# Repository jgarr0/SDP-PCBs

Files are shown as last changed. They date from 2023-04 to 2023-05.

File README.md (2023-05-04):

# SDP-PCBs
Hub and Outlet Motherboard Schematics and PCB Layouts for Smart Power Outlet System
#Hub PCB Schematic


## Hub PCB Layout


## Hub PCB Render


## Assembled hub


## Outlet PCB Schematic


## Outlet PCB Layout


## Outlet PCB Render


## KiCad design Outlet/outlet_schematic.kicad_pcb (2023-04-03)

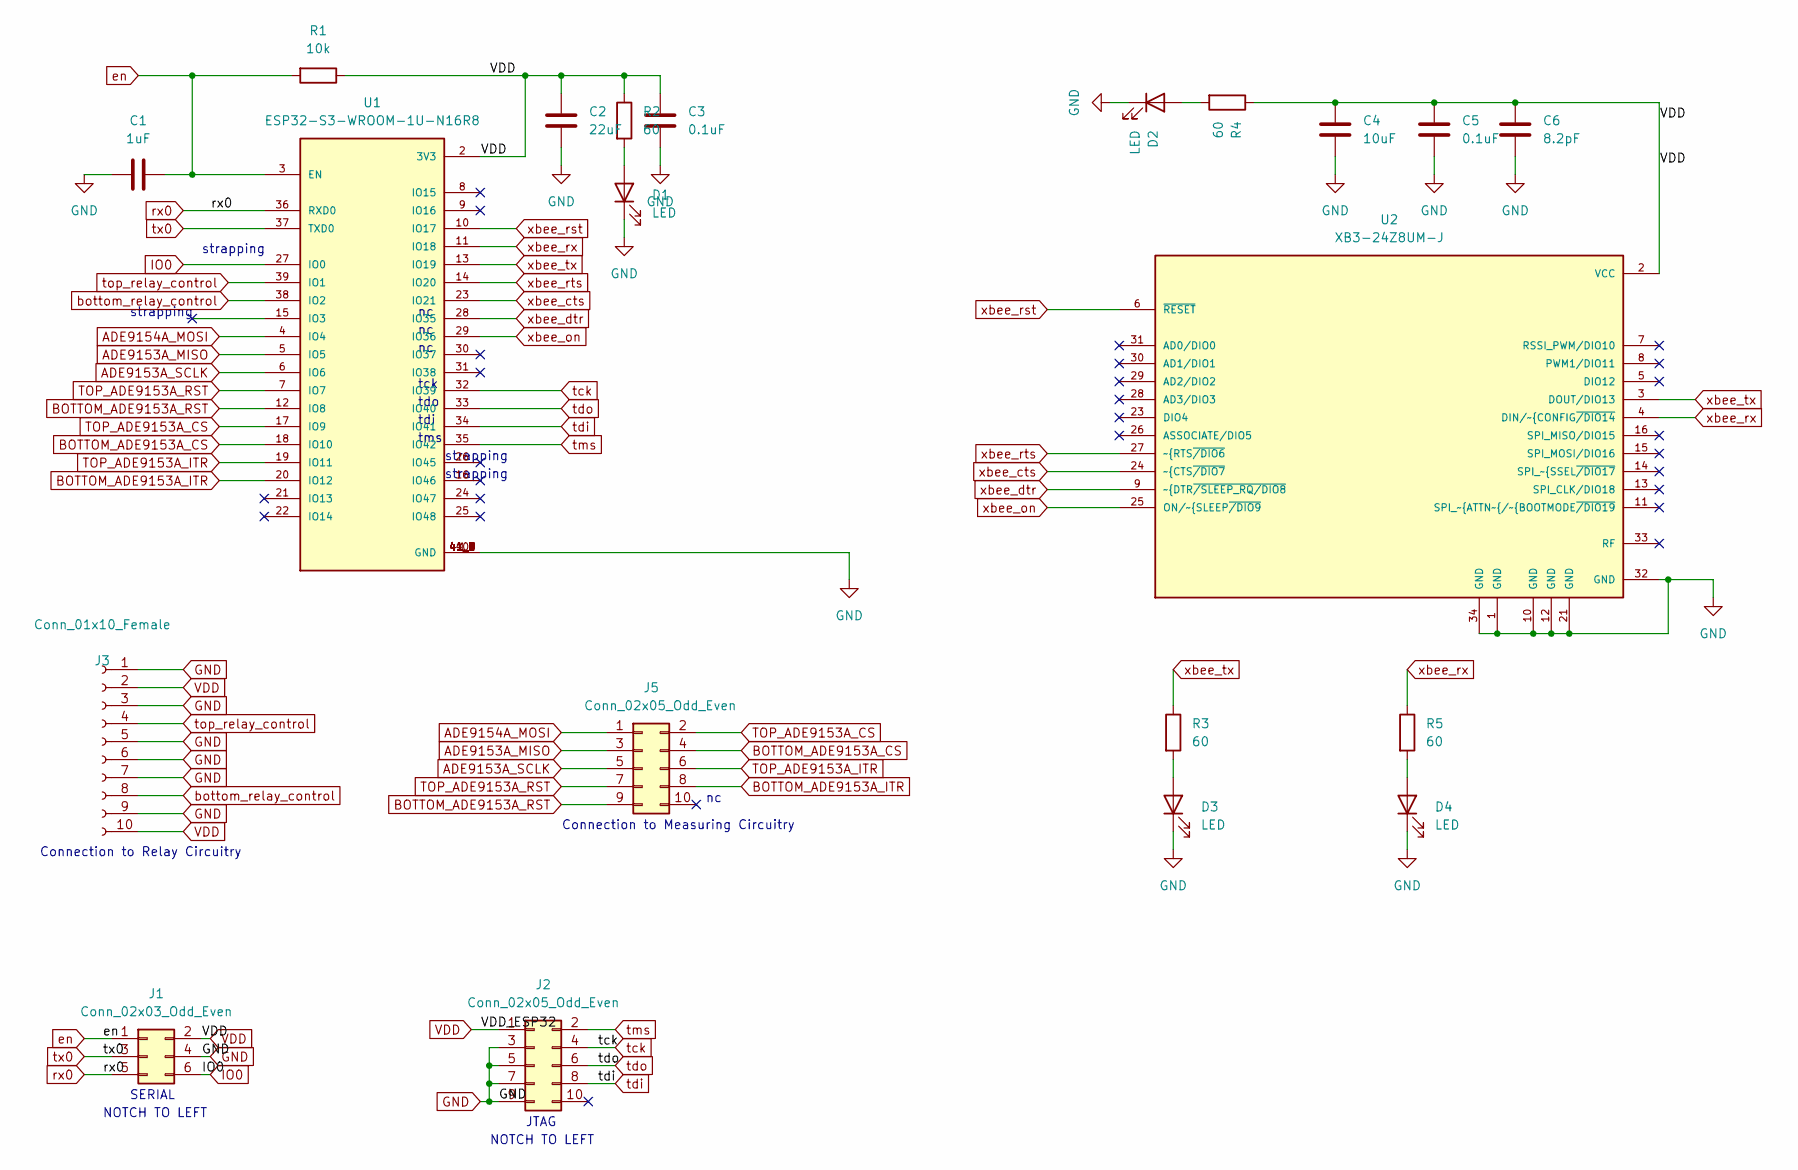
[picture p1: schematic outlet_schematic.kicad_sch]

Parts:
C1: 1uF; C_1206_3216Metric
C2: 22uF; C_1206_3216Metric
C3, C5: 0.1uF; C_1206_3216Metric
C4: 10uF; C_1206_3216Metric
C6: 8.2pF; C_1206_3216Metric
D1, D2, D3, D4: LED; LED_1206_3216Metric
J1: Conn_02x03_Odd_Even; IDC-Header_2x03_P2.54mm_Vertical
J2: Conn_02x05_Odd_Even; IDC-Header_2x05_P2.54mm_Vertical
J3: Conn_01x10_Female; JST_PHD_S10B-PHDSS_2x05_P2.00mm_Horizontal
J5: Conn_02x05_Odd_Even; JST_PHD_S10B-PHDSS_2x05_P2.00mm_Horizontal
R1: 10k; R_1206_3216Metric
R2, R3, R4, R5: 60; R_1206_3216Metric
U1: ESP32-S3-WROOM-1U-N16R8; XCVR_ESP32-S3-WROOM-1U; PARTREV v1.1
U2: XB3-24Z8UM-J; XCVR_XB3-24Z8UM-J

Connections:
ADE9153A_MISO: J5.3, U1.5 (IO5)
ADE9153A_SCLK: J5.5, U1.6 (IO6)
ADE9154A_MOSI: J5.1, U1.4 (IO4)
BOTTOM_ADE9153A_CS: J5.4, U1.18 (IO10)
BOTTOM_ADE9153A_ITR: J5.8, U1.20 (IO12)
BOTTOM_ADE9153A_RST: J5.9, U1.12 (IO8)
GND: C1.2, C2.2, C3.2, C4.2, C5.2, C6.2, D1.1 (K), D2.1 (K), D3.1 (K), D4.1 (K), J1.4, J2.3, J2.5, J2.7, J2.9, J3.1, J3.3, J3.5, J3.6, J3.7, J3.9, U1.1 (GND), U1.40 (GND), U1.41_1 (GND), U1.41_2 (GND), U1.41_3 (GND), U1.41_4 (GND), U1.41_5 (GND), U1.41_6 (GND), U1.41_7 (GND), U1.41_8 (GND), U1.41_9 (GND), U2.1 (GND), U2.10 (GND), U2.12 (GND), U2.21 (GND), U2.32 (GND), U2.34 (GND)
IO0: J1.6, U1.27 (IO0)
unnamed: D1.2 (A), R2.2
unnamed: D2.2 (A), R4.2
unnamed: D3.2 (A), R3.2
unnamed: D4.2 (A), R5.2
TOP_ADE9153A_CS: J5.2, U1.17 (IO9)
TOP_ADE9153A_ITR: J5.6, U1.19 (IO11)
TOP_ADE9153A_RST: J5.7, U1.7 (IO7)
VDD: C2.1, C3.1, C4.1, C5.1, C6.1, J1.2, J2.1, J3.2, J3.10, R1.1, R2.1, R4.1, U1.2 (3V3), U2.2 (VCC)
bottom_relay_control: J3.8, U1.38 (IO2)
en: C1.1, J1.1, R1.2, U1.3 (EN)
rx0: J1.5, U1.36 (RXD0)
tck: J2.4, U1.32 (IO39)
tdi: J2.8, U1.34 (IO41)
tdo: J2.6, U1.33 (IO40)
tms: J2.2, U1.35 (IO42)
top_relay_control: J3.4, U1.39 (IO1)
tx0: J1.3, U1.37 (TXD0)
xbee_cts: U1.23 (IO21), U2.24 (~CTS~{/DIO7)
xbee_dtr: U1.28 (IO35), U2.9 (~DTR~{/SLEEP_RQ/DIO8)
xbee_on: U1.29 (IO36), U2.25 (ON/~SLEEP~{/DIO9)
xbee_rst: U1.10 (IO17), U2.6 (~RESET)
xbee_rts: U1.14 (IO20), U2.27 (~RTS~{/DIO6)
xbee_rx: R5.1, U1.11 (IO18), U2.4 (DIN/~CONFIG~{/DIO14)
xbee_tx: R3.1, U1.13 (IO19), U2.3 (DOUT/DIO13)

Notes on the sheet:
tms
strapping
Connection to Relay Circuitry
tdi
JTAG
NOTCH TO LEFT
tck
tdo
Connection to Measuring Circuitry
SERIAL

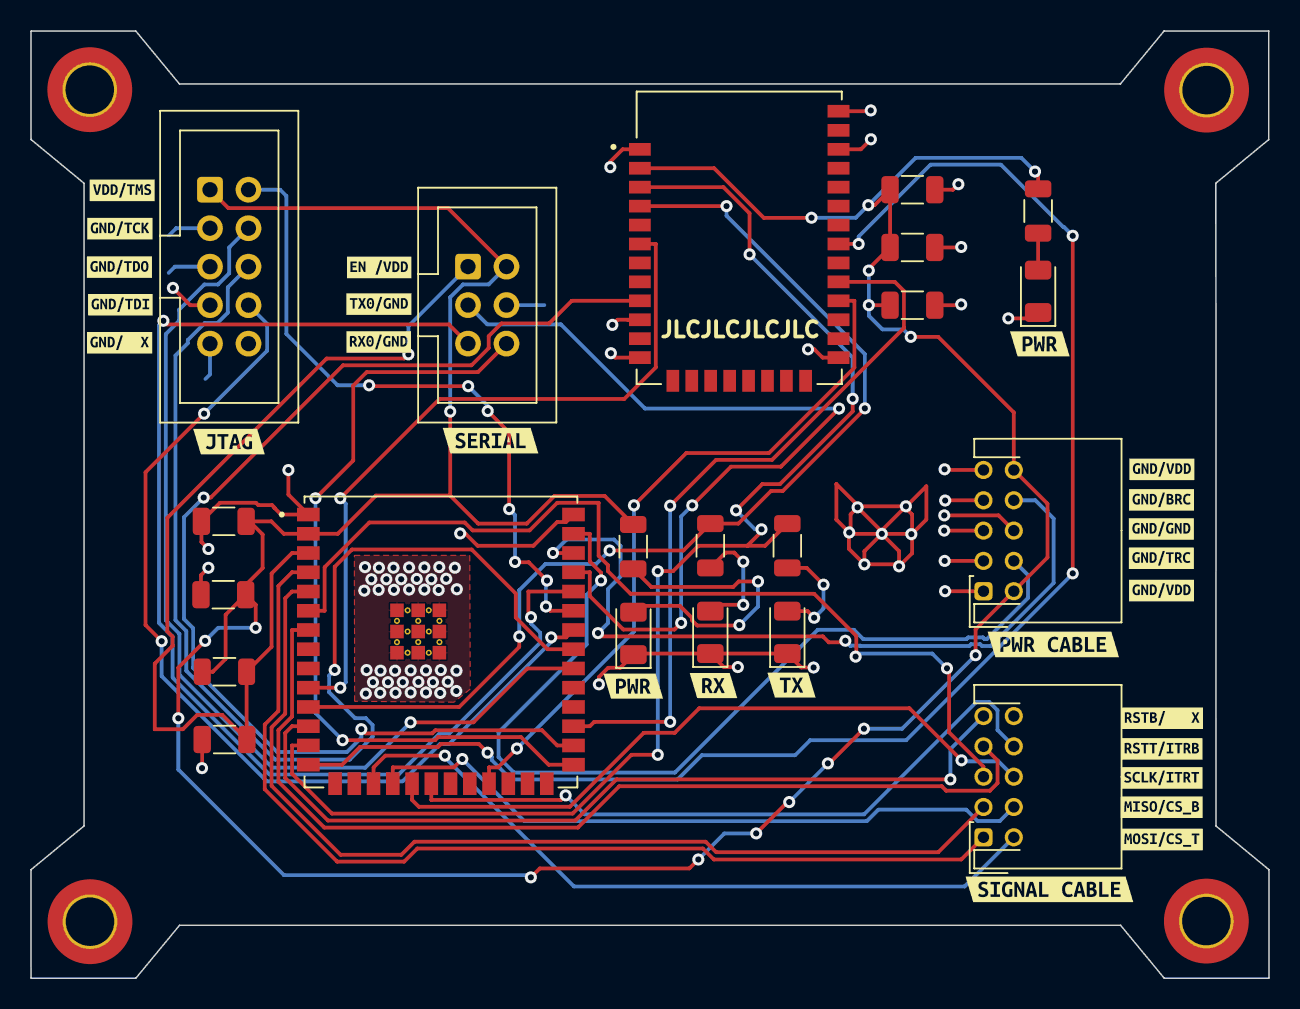
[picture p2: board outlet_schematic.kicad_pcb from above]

Board: 2 copper layers, 81.7 x 62.5 mm, 51 parts (0 on the bottom side), 32 nets.

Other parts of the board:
MP1, MP2, MP3, MP4: MountingHole_3.2mm_M3_DIN965_Pad_TopBottom
kibuzzard-6423A409: G***; kibuzzard-6423A409
kibuzzard-64222CB8, kibuzzard-64222CB8#2: G***; kibuzzard-64222CB8
kibuzzard-64222D10: G***; kibuzzard-64222D10
kibuzzard-64222D21: G***; kibuzzard-64222D21
kibuzzard-64222DA8: G***; kibuzzard-64222DA8
kibuzzard-64222DBC: G***; kibuzzard-64222DBC
kibuzzard-64222E4F: G***; kibuzzard-64222E4F
kibuzzard-64222ED4: G***; kibuzzard-64222ED4
kibuzzard-64222F0B: G***; kibuzzard-64222F0B
kibuzzard-64222F2D: G***; kibuzzard-64222F2D
kibuzzard-64222F16: G***; kibuzzard-64222F16
kibuzzard-6422303A: G***; kibuzzard-6422303A
kibuzzard-6422317A: G***; kibuzzard-6422317A
kibuzzard-6422318F: G***; kibuzzard-6422318F
kibuzzard-6422332A: G***; kibuzzard-6422332A
kibuzzard-6422333F: G***; kibuzzard-6422333F
kibuzzard-64223004: G***; kibuzzard-64223004
kibuzzard-64223022: G***; kibuzzard-64223022
kibuzzard-64223074: G***; kibuzzard-64223074
kibuzzard-64223167: G***; kibuzzard-64223167
kibuzzard-64223170: G***; kibuzzard-64223170
kibuzzard-64223187: G***; kibuzzard-64223187
kibuzzard-64223322: G***; kibuzzard-64223322
kibuzzard-64223346: G***; kibuzzard-64223346
kibuzzard-64223357: G***; kibuzzard-64223357

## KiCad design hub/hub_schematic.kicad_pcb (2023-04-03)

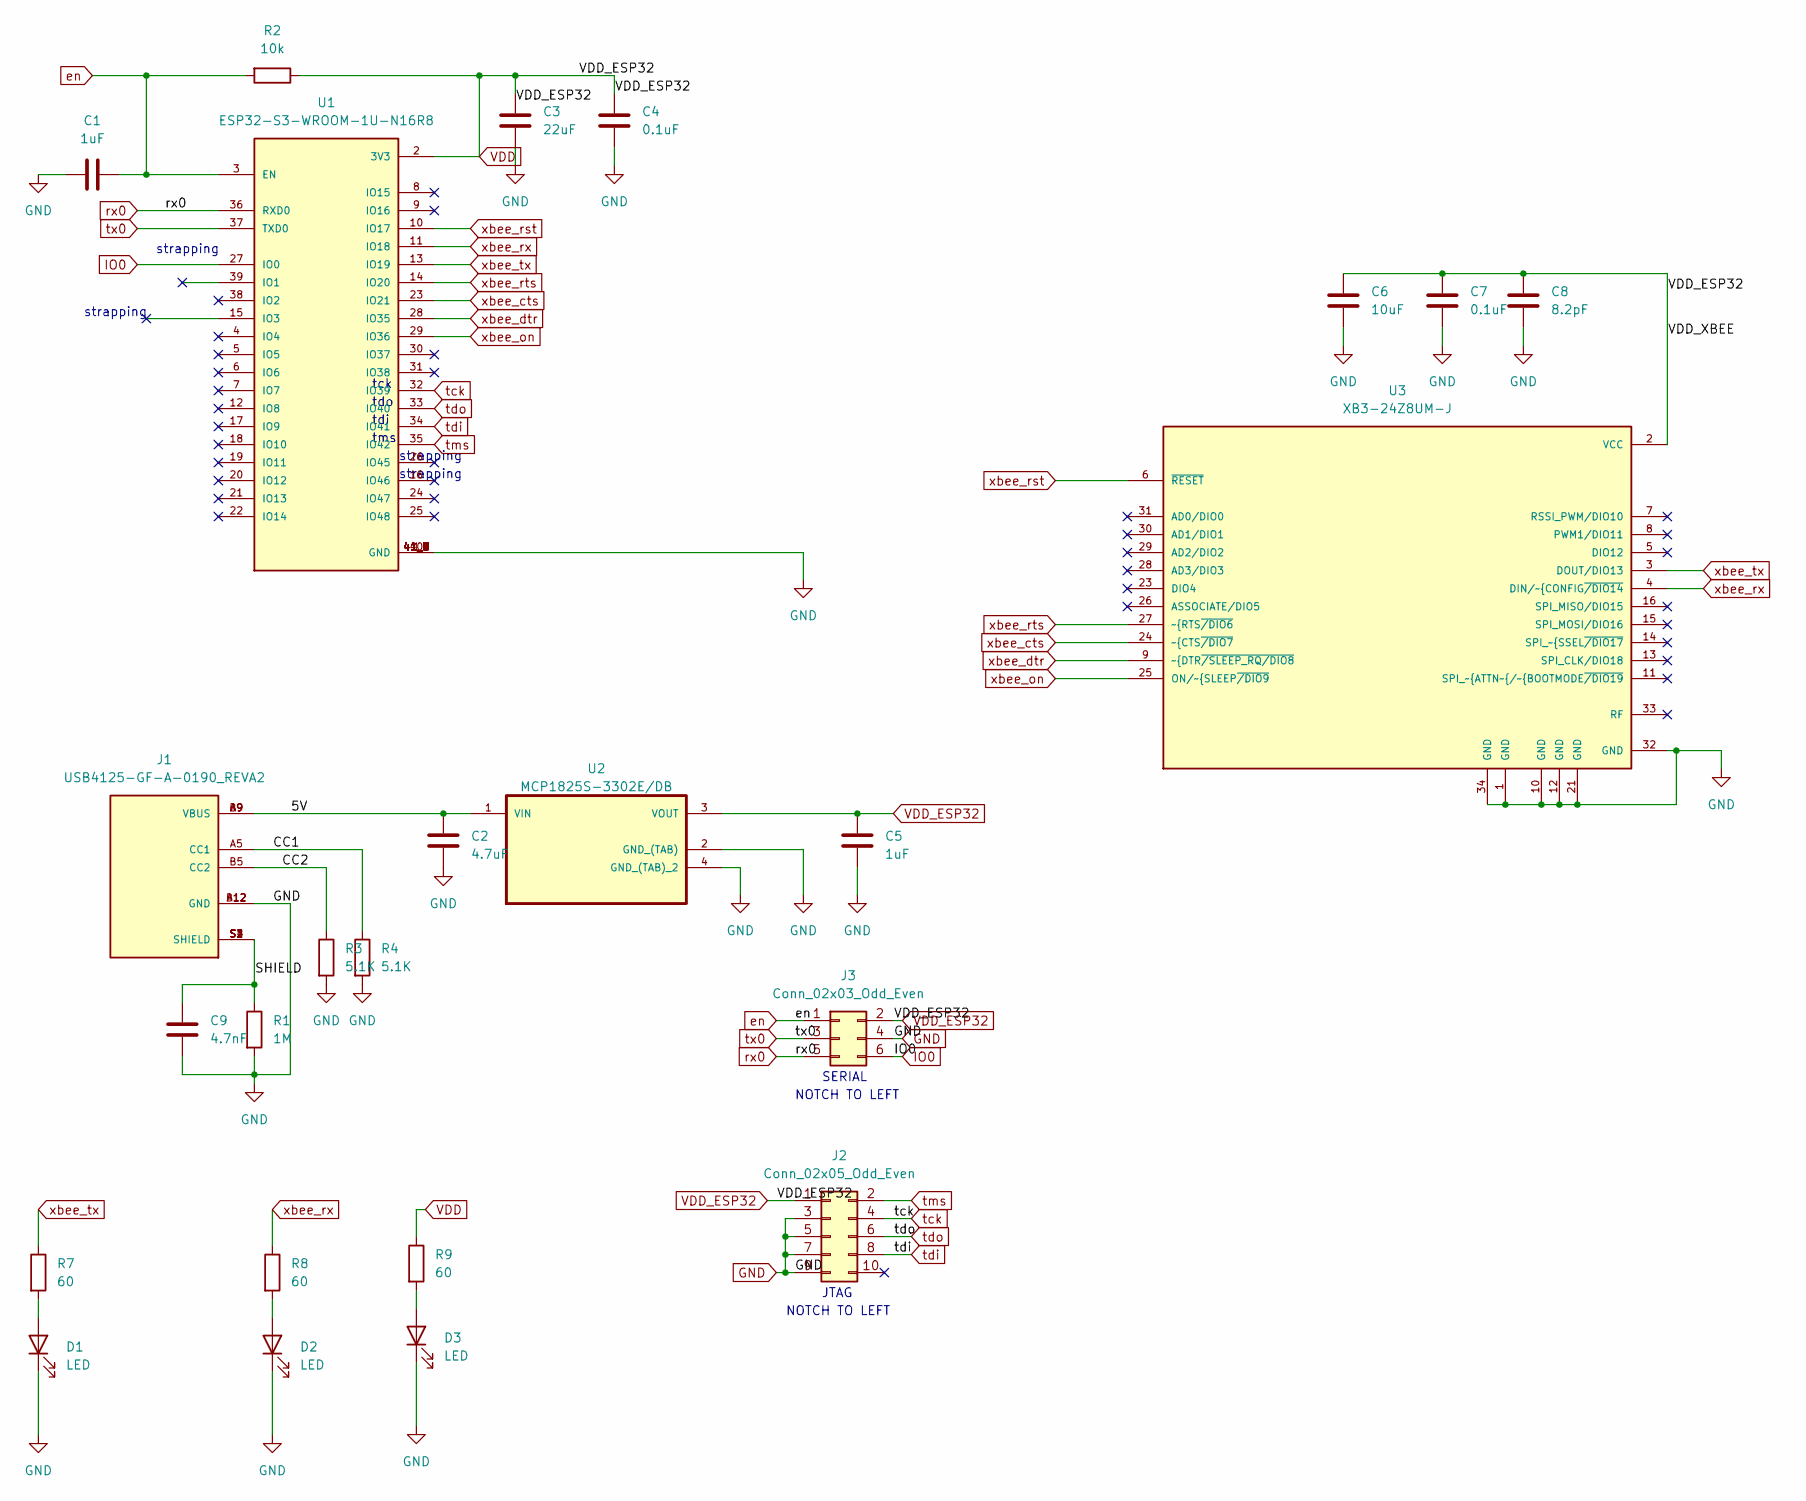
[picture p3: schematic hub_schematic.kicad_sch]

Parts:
C1, C5: 1uF; C_1206_3216Metric_Pad1.33x1.80mm_HandSolder
C2: 4.7uF; C_1206_3216Metric_Pad1.33x1.80mm_HandSolder
C3: 22uF; C_1206_3216Metric_Pad1.33x1.80mm_HandSolder
C4, C7: 0.1uF; C_1206_3216Metric_Pad1.33x1.80mm_HandSolder
C6: 10uF; C_1206_3216Metric_Pad1.33x1.80mm_HandSolder
C8: 8.2pF; C_1206_3216Metric_Pad1.33x1.80mm_HandSolder
C9: 4.7nF; C_1206_3216Metric_Pad1.33x1.80mm_HandSolder
D1, D2, D3: LED; LED_1206_3216Metric_Pad1.42x1.75mm_HandSolder
J1: USB4125-GF-A-0190_REVA2; GCT_USB4125-GF-A-0190_REVA2; PARTREV Rev A2
J2: Conn_02x05_Odd_Even; IDC-Header_2x05_P2.54mm_Vertical
J3: Conn_02x03_Odd_Even; IDC-Header_2x03_P2.54mm_Vertical
R1: 1M; R_1206_3216Metric_Pad1.30x1.75mm_HandSolder
R2: 10k; R_1206_3216Metric_Pad1.30x1.75mm_HandSolder
R3, R4: 5.1K; R_1206_3216Metric_Pad1.30x1.75mm_HandSolder
R7, R8, R9: 60; R_1206_3216Metric_Pad1.30x1.75mm_HandSolder
U1: ESP32-S3-WROOM-1U-N16R8; XCVR_ESP32-S3-WROOM-1U; PARTREV v1.1
U2: MCP1825S-3302E/DB; SOT230P700X180-4N
U3: XB3-24Z8UM-J; XCVR_XB3-24Z8UM-J

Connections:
/5V: C2.1, J1.A9 (VBUS), J1.B9 (VBUS), U2.1 (VIN)
/CC1: J1.A5 (CC1), R4.1
/CC2: J1.B5 (CC2), R3.1
/SHIELD: C9.1, J1.S1 (SHIELD), J1.S2 (SHIELD), J1.S3 (SHIELD), J1.S4 (SHIELD), R1.1
GND: C1.2, C2.2, C3.2, C4.2, C5.2, C6.2, C7.2, C8.2, C9.2, D1.1 (K), D2.1 (K), D3.1 (K), J1.A12 (GND), J1.B12 (GND), J2.3, J2.5, J2.7, J2.9, J3.4, R1.2, R3.2, R4.2, U1.1 (GND), U1.40 (GND), U1.41_1 (GND), U1.41_2 (GND), U1.41_3 (GND), U1.41_4 (GND), U1.41_5 (GND), U1.41_6 (GND), U1.41_7 (GND), U1.41_8 (GND), U1.41_9 (GND), U2.2 (GND_(TAB)), U2.4 (GND_(TAB)_2), U3.1 (GND), U3.10 (GND), U3.12 (GND), U3.21 (GND), U3.32 (GND), U3.34 (GND)
IO0: J3.6, U1.27 (IO0)
unnamed: D1.2 (A), R7.2
unnamed: D2.2 (A), R8.2
unnamed: D3.2 (A), R9.2
VDD: C3.1, C4.1, C5.1, C6.1, C7.1, C8.1, J2.1, J3.2, R2.1, R9.1, U1.2 (3V3), U2.3 (VOUT), U3.2 (VCC)
en: C1.1, J3.1, R2.2, U1.3 (EN)
rx0: J3.5, U1.36 (RXD0)
tck: J2.4, U1.32 (IO39)
tdi: J2.8, U1.34 (IO41)
tdo: J2.6, U1.33 (IO40)
tms: J2.2, U1.35 (IO42)
tx0: J3.3, U1.37 (TXD0)
xbee_cts: U1.23 (IO21), U3.24 (~CTS~{/DIO7)
xbee_dtr: U1.28 (IO35), U3.9 (~DTR~{/SLEEP_RQ/DIO8)
xbee_on: U1.29 (IO36), U3.25 (ON/~SLEEP~{/DIO9)
xbee_rst: U1.10 (IO17), U3.6 (~RESET)
xbee_rts: U1.14 (IO20), U3.27 (~RTS~{/DIO6)
xbee_rx: R8.1, U1.11 (IO18), U3.4 (DIN/~CONFIG~{/DIO14)
xbee_tx: R7.1, U1.13 (IO19), U3.3 (DOUT/DIO13)

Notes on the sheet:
tms
strapping
tdi
JTAG
NOTCH TO LEFT
tck
tdo
SERIAL

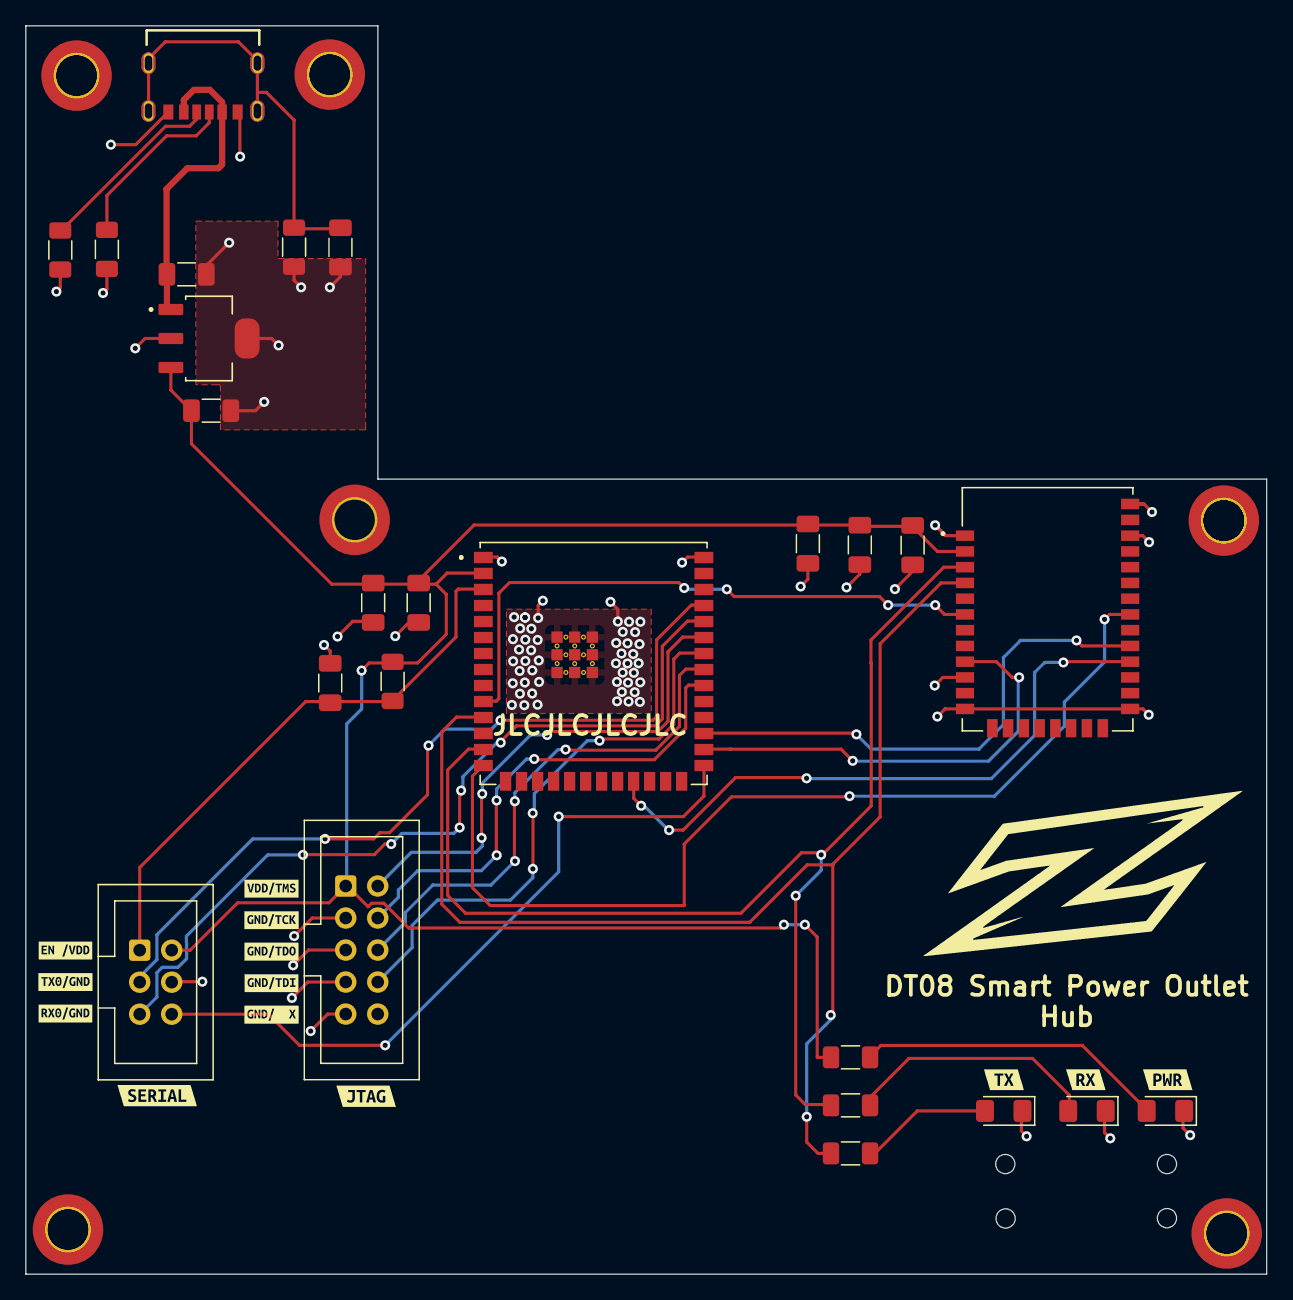
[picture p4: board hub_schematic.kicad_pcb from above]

Board: 2 copper layers, 98.5 x 99.1 mm, 38 parts (0 on the bottom side), 24 nets.

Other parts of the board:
kibuzzard-6423A4A2: G***; kibuzzard-6423A4A2
kibuzzard-6423A4AE: G***; kibuzzard-6423A4AE
kibuzzard-6423A4B6: G***; kibuzzard-6423A4B6
kibuzzard-6423A4BC: G***; kibuzzard-6423A4BC
kibuzzard-6423A4C5: G***; kibuzzard-6423A4C5
kibuzzard-6423A5A2: G***; kibuzzard-6423A5A2
kibuzzard-6423A5A6: G***; kibuzzard-6423A5A6
kibuzzard-6423A5AD: G***; kibuzzard-6423A5AD
kibuzzard-6423A409: G***; kibuzzard-6423A409
kibuzzard-6423A486: G***; kibuzzard-6423A486
kibuzzard-6422303A: G***; kibuzzard-6422303A
kibuzzard-64223004: G***; kibuzzard-64223004
kibuzzard-64223022: G***; kibuzzard-64223022
